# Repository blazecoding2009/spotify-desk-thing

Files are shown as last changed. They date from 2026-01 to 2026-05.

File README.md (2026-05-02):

# spotify desk thing
### custom made pcb to be like the [spotify car thing](https://support.spotify.com/us/article/car-thing-discontinued/) (sadly discontinued)

yeah this is something i literally thought of while sitting and listening to music and i think it'd look cool lol
the whole project is pretty self-explanatory, a replacement to the spotify desk think, you could use this as a deskpad with diff firmware too!!






## Features

- ESP32-S3
- 3.5” 480×320 SPI TFT display
- Capacitive touchscreen (GT911)
- SD card music playback
- I²S DAC (PCM5242)
- Differential headphone amp (TPA6132A2)
- Rotary encoder for volume + play/pause
- Headphone output (3.5mm jack)

---

## Hardware Overview

### Main Components

- **ESP32-S3-WROOM-1**
- **ST7796 3.5” TFT Display**
- **GT911 Capacitive Touch (on display)**
- **PCM5242 DAC**
- **TPA6132A2 Headphone Amplifier**
- **MicroSD Card **
- **Rotary Encoder with push button**

## Firmware Overview

The firmware is written using **ESP-IDF**.

### Tasks

- **UI Task**
  - Draws the interface
  - Handles play/pause and volume updates

- **Input Task**
  - Reads touch input
  - Reads rotary encoder events
  - Pushes events into a queue

- **Audio Task**
  - Plays WAV files
  - Handles beeps and stop commands
 
## Future Ideas

- Spotify / Wi-Fi streaming
- Album art
- Playlists
- Battery power
- Better UI animations

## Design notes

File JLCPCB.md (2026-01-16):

PCBA Type	Economic
Assembly Side	Top Side
PCBA Qty 2
Tooling holes	Added by JLCPCB
Confirm Parts Placement	No
Bake Components	No
Photo Confirmation	No
Board Cleaning	No
Conformal Coating (cleaning included)	No
Packaging	Antistatic bubble film
Depanel boards & edge rail before delivery	No
Solder Paste	High temp.
Flying Probe Test	No
Add paste for unpopulated pad & step stencil opening	No
Nitrogen reflow soldering	Yes (for Economic)
Function test	No
PCBA remark	No
File provided as	Complete File, just proceed with my own files
Panel Format	1 * 1
Build Time	3 - 4 days
Stencil Storage	No
Fixture Storage	No
Gross Weight	





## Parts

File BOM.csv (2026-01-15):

Name | Quantity | Cost (CAD) incl. shipping | Cost (USD) | Link
ESP32-S3 N16R8 | 1 | $20.76 | $14.91 | https://www.aliexpress.com/item/1005004815894336.html?mp=1
3.5in IPS Touch Display | 1 | $28.08 | $20.17 | https://www.aliexpress.com/item/1005006112241357.html?mp=1
EC11E Encoder | 1 | $6.41 | $4.61 | https://www.aliexpress.com/item/1005007644083514.html?mp=1
PCB | 1 | $84.88 | $61.25 | JLCPCB
M3x5mm screws | 6 |  |  | already have
M3 5mm wide heatset inserts | 6 | $7.20 | $5.20 | https://www.aliexpress.com/item/1005006838108683.html?curPageLogUid=nqhrvDMGyt7B
3d printed case | 1 |  |  | by me
 |  | Total | $107.87

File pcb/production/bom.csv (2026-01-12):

Designator | Footprint | Quantity | Value | LCSC Part #
BOOT1 | SW_SPST_CK_KMS2xxG | 1 | BOOT | C221784
C1, C12, C13, C18, C4, C6, C8 | 0402 | 7 | 0.1uF | C1525
C10, C15, C7 | 0402 | 3 | 1uF | C52923
C11, C19 | 0402 | 2 | 10uF | C15525
C14, C16, C2, C5, C9 | 0402 | 5 | 2.2uF | C12530
C17 | 0603 | 1 | 1uF | C15849
C3 | 0402 | 1 | 22uF | C415703
F1 | FUSC1608X100N | 1 | 0603L100SLYR | C207017
J1 | USB_C_Receptacle_HRO_TYPE-C-31-M-12 | 1 | USB_C_Receptacle_USB2.0_16P | C165948
J2 | CUI_SJ-3523-SMT-TR | 1 | AudioJack3_Ground | C4991872
J3 | TE_1-1734839-4_1x14-1MP_P0.5mm_Horizontal | 1 | ST7796
L1 | 0805 | 1 | 2.2uH | C1043
PS1 | SON50P200X200X80-9N | 1 | TPS62162DSGR | C40256
R1, R2, R3, R4, R5 | 0603 | 5 | 10k | C25804
R10, R9 | 0603 | 2 | 27ohm | C25190
R11, R7 | 0603 | 2 | 10ohm | C22859
R12, R13 | 0603 | 2 | 4.7k | C23162
R14, R8 | 0402 | 2 | 5.1k | C25905
R6 | 0603 | 1 | 100k | C25803
RESET1 | SW_SPST_CK_KMS2xxG | 1 | RESET | C221784
U1 | RHB32_3P45X3P45_TEX | 1 | PCM5242RHBR
U2 | WQFN-16-1EP_3x3mm_P0.5mm_EP1.6x1.6mm_ThermalVias | 1 | TPA6132A2RTER | TPA6132A2RTER
U3 | EC11E18244A5_ALPS | 1 | EC11E18244A5
U4 | XCVR_ESP32-S3-WROOM-1-N4 | 1 | ESP32-S3-WROOM-1-N16R8
U5 | SOT-23-6 | 1 | USBLC6-2SC6

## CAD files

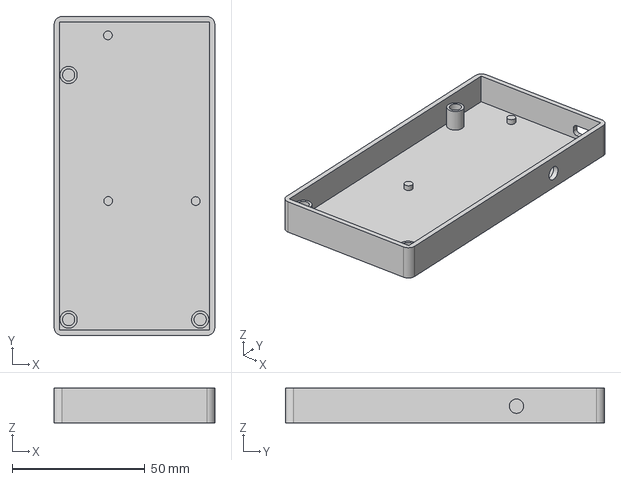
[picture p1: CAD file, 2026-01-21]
case/case_bottom.step
60.4 x 120.0 x 13.0 mm

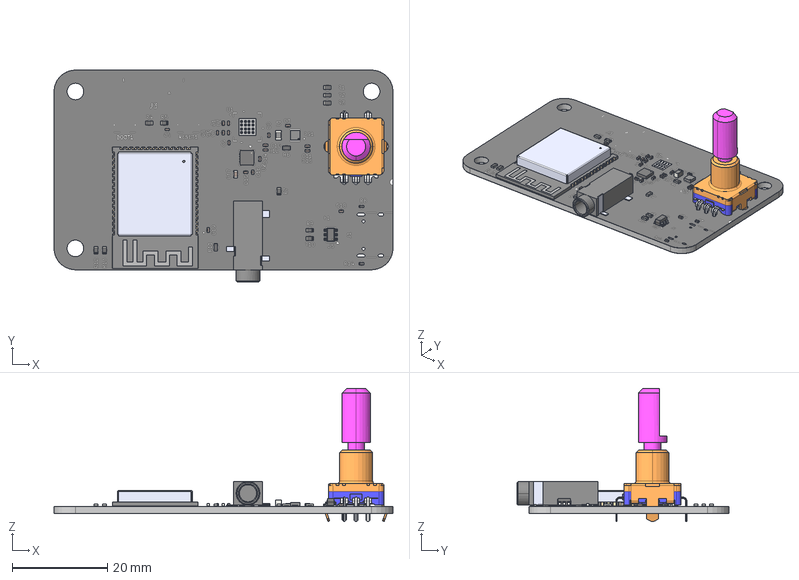
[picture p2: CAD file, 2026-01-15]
pcb/spotify desk thing.step
71.3 x 44.6 x 28.0 mm
R_0402_1005Metric x 2
C_0402_1005Metric x 18
R_0603_1608Metric x 12
SJ-3523-SMT-TR
SOT-23-6
TPS62162DSGR
L_0805_2012Metric
WQFN-16-1EP_3x3mm_P0.5mm_EP1.6x1.6mm
C_0603_1608Metric
ESP32-S3-WROOM-1-N4
ec11e18244a5
spotify desk thing_silkscreen x 2
spotify desk thing_soldermask x 2
spotify desk thing_PCB

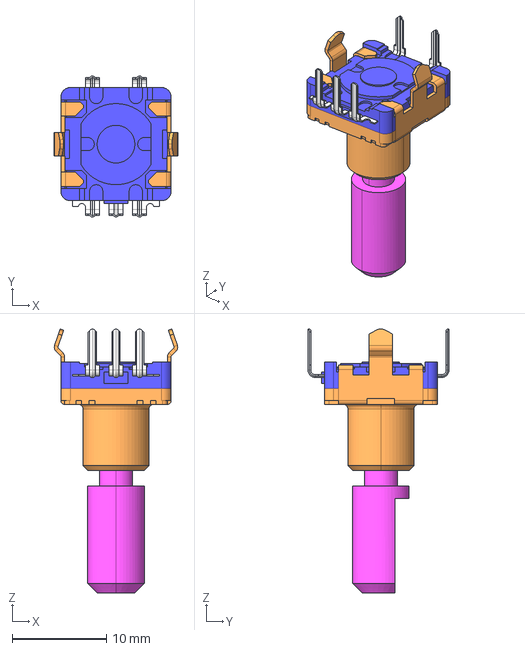
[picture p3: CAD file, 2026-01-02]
pcb/symbols/EC11E/ec11e18244a5.stp
13.1 x 15.0 x 28.0 mm

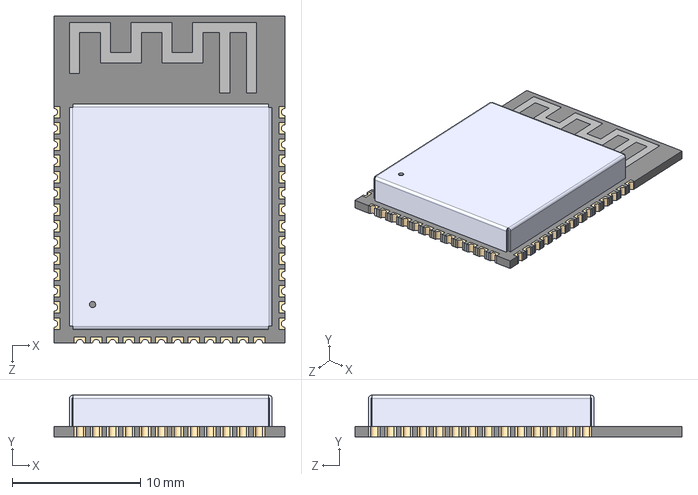
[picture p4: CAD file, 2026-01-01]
pcb/symbols/ESP32_S3_WROOM_1_N4/ESP32-S3-WROOM-1-N4.step
18.0 x 3.25 x 25.5 mm

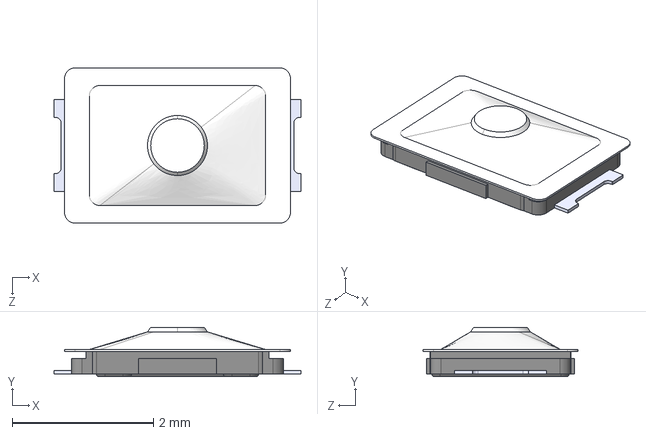
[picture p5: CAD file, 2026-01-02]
pcb/symbols/EVP_AWED4A/EVP-AWED4A.step
3.50 x 0.7 x 2.20 mm

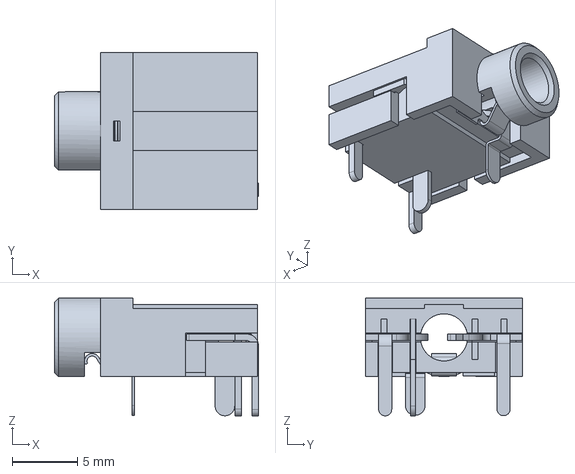
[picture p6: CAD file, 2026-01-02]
pcb/symbols/Lumberg_KLBR_4.stp
15.6 x 12.0 x 9.00 mm

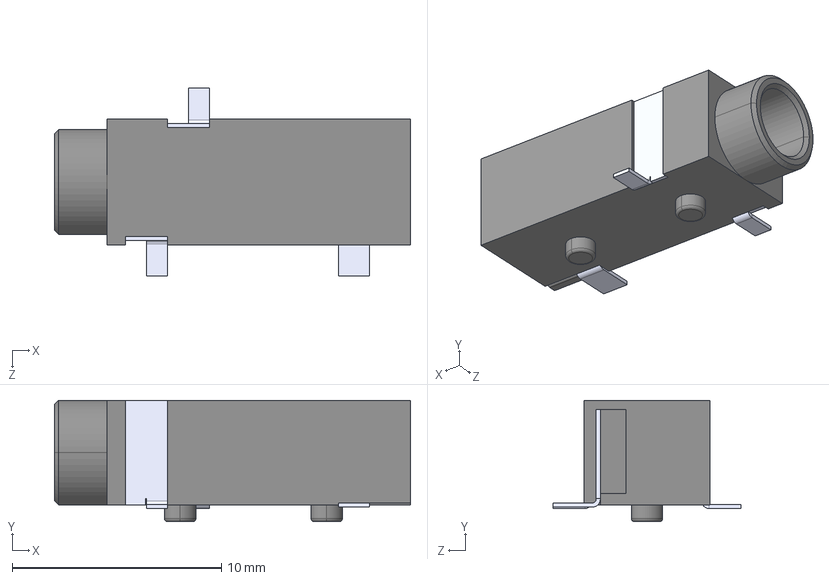
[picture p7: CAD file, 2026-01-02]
pcb/symbols/SJ_3523_SMT_TR/SJ-3523-SMT-TR.step
17.0 x 5.80 x 9.00 mm

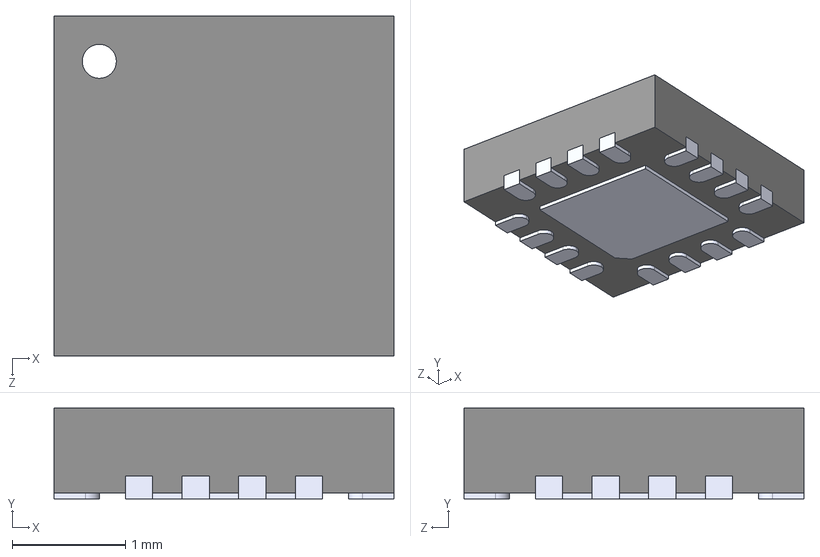
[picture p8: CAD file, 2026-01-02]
pcb/symbols/TPA6132A2RTER/TPA6132A2RTER.step
3.00 x 0.8 x 3.00 mm

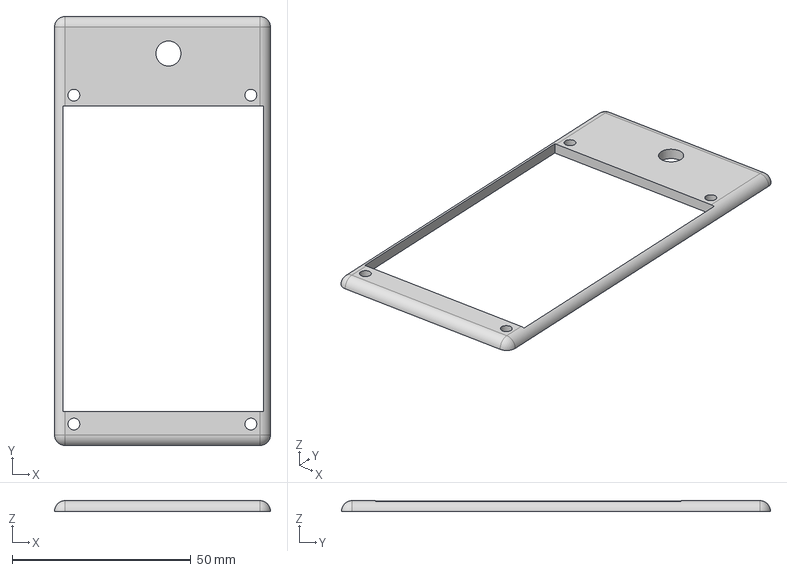
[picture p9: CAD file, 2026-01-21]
case/case_top.step
60.4 x 120.0 x 3.00 mm

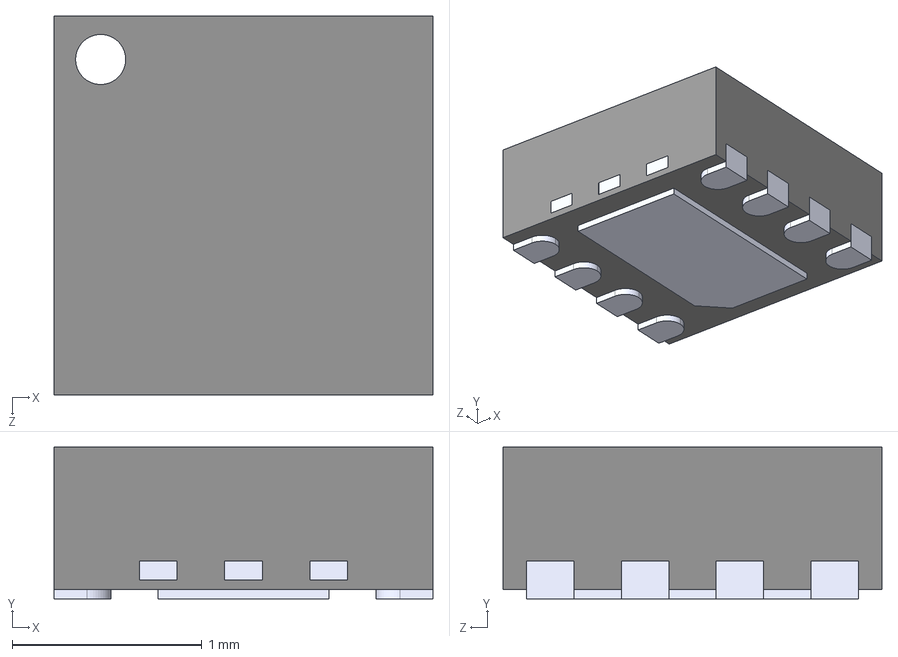
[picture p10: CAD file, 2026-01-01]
pcb/symbols/TPS62162DSGR/TPS62162DSGR.step
2.00 x 0.8 x 2.00 mm

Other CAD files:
case/case.f3z
pcb/spotify desk thing.stl

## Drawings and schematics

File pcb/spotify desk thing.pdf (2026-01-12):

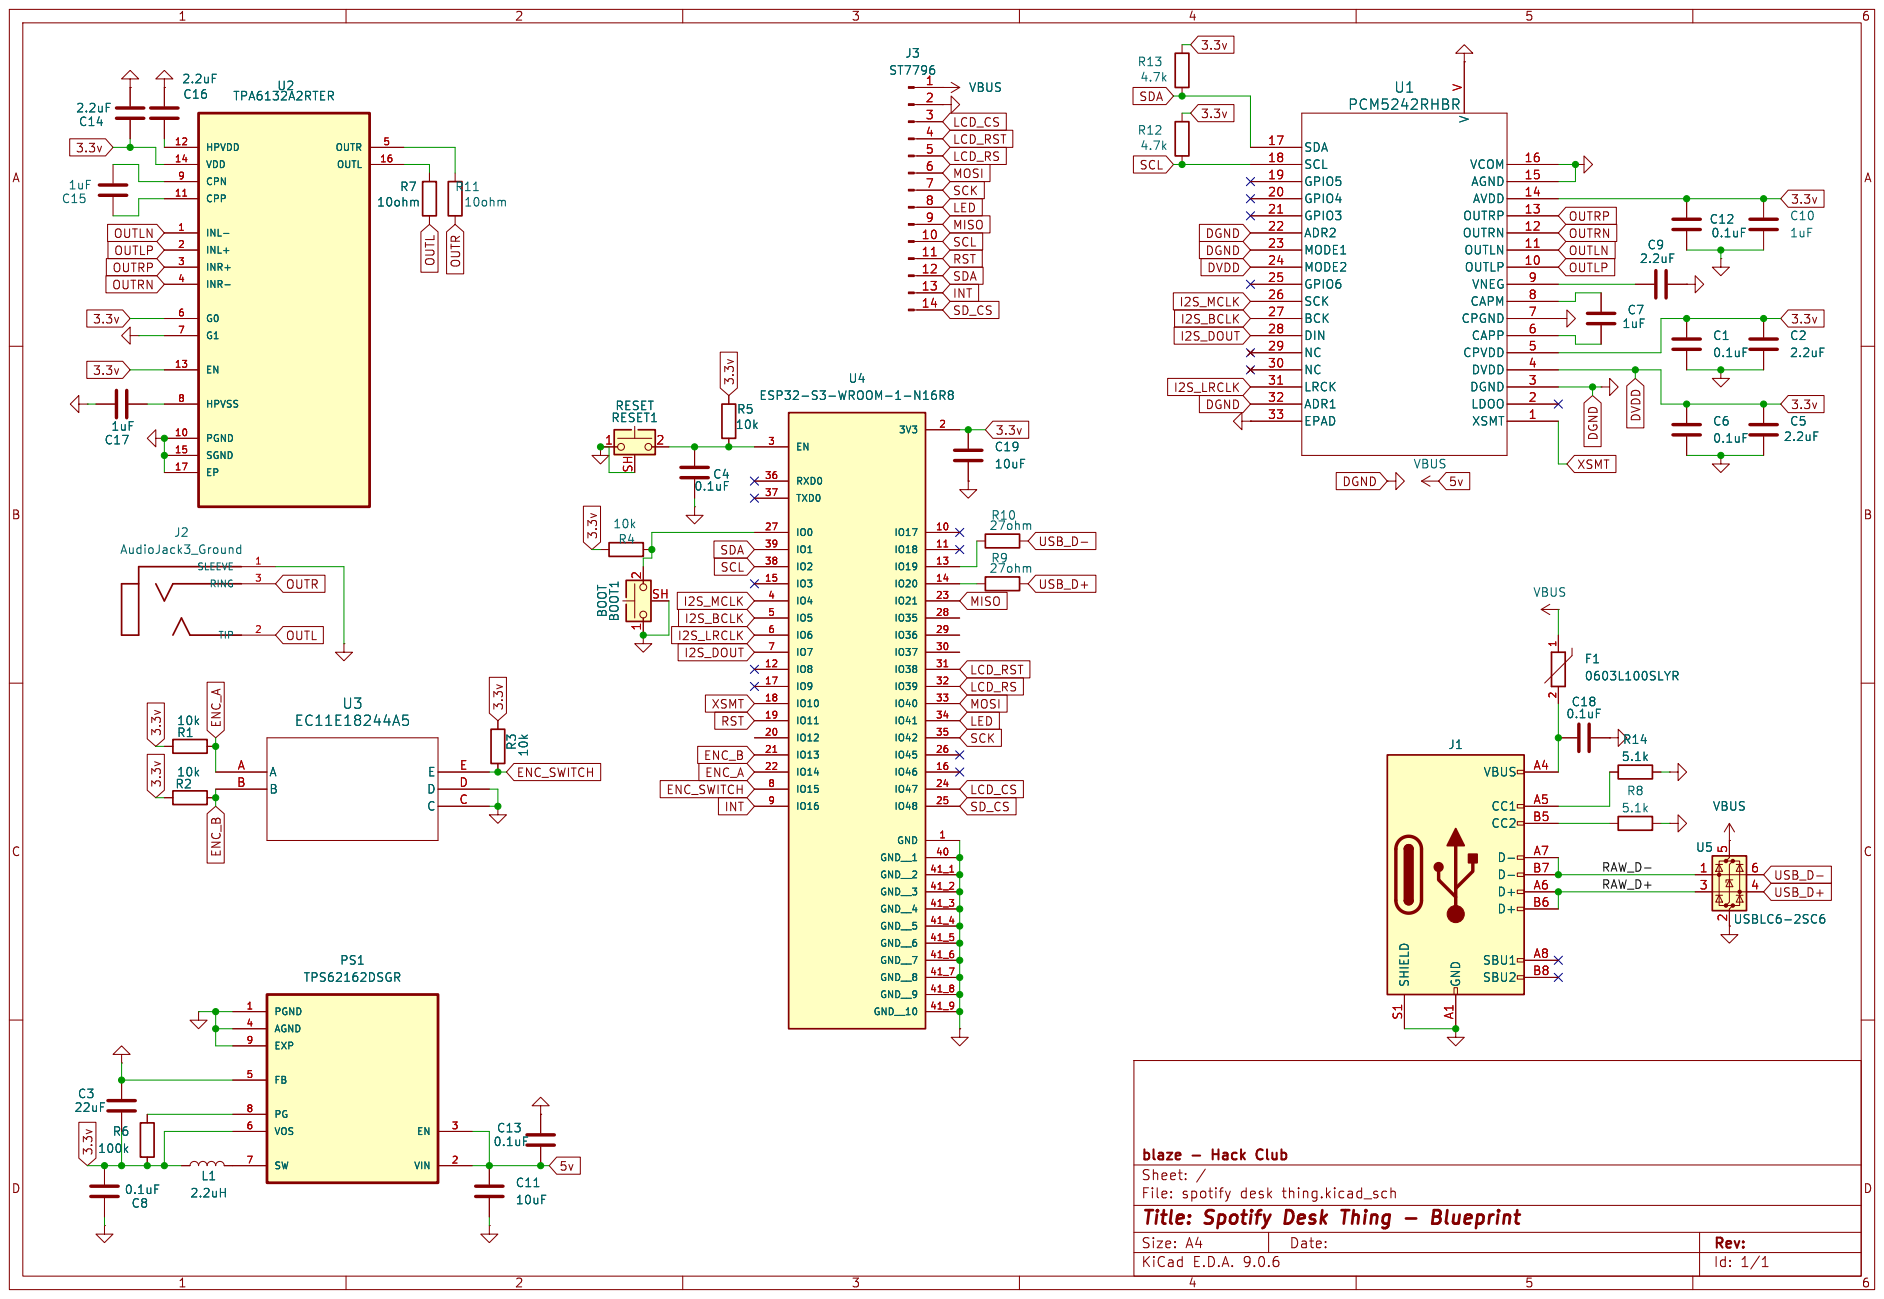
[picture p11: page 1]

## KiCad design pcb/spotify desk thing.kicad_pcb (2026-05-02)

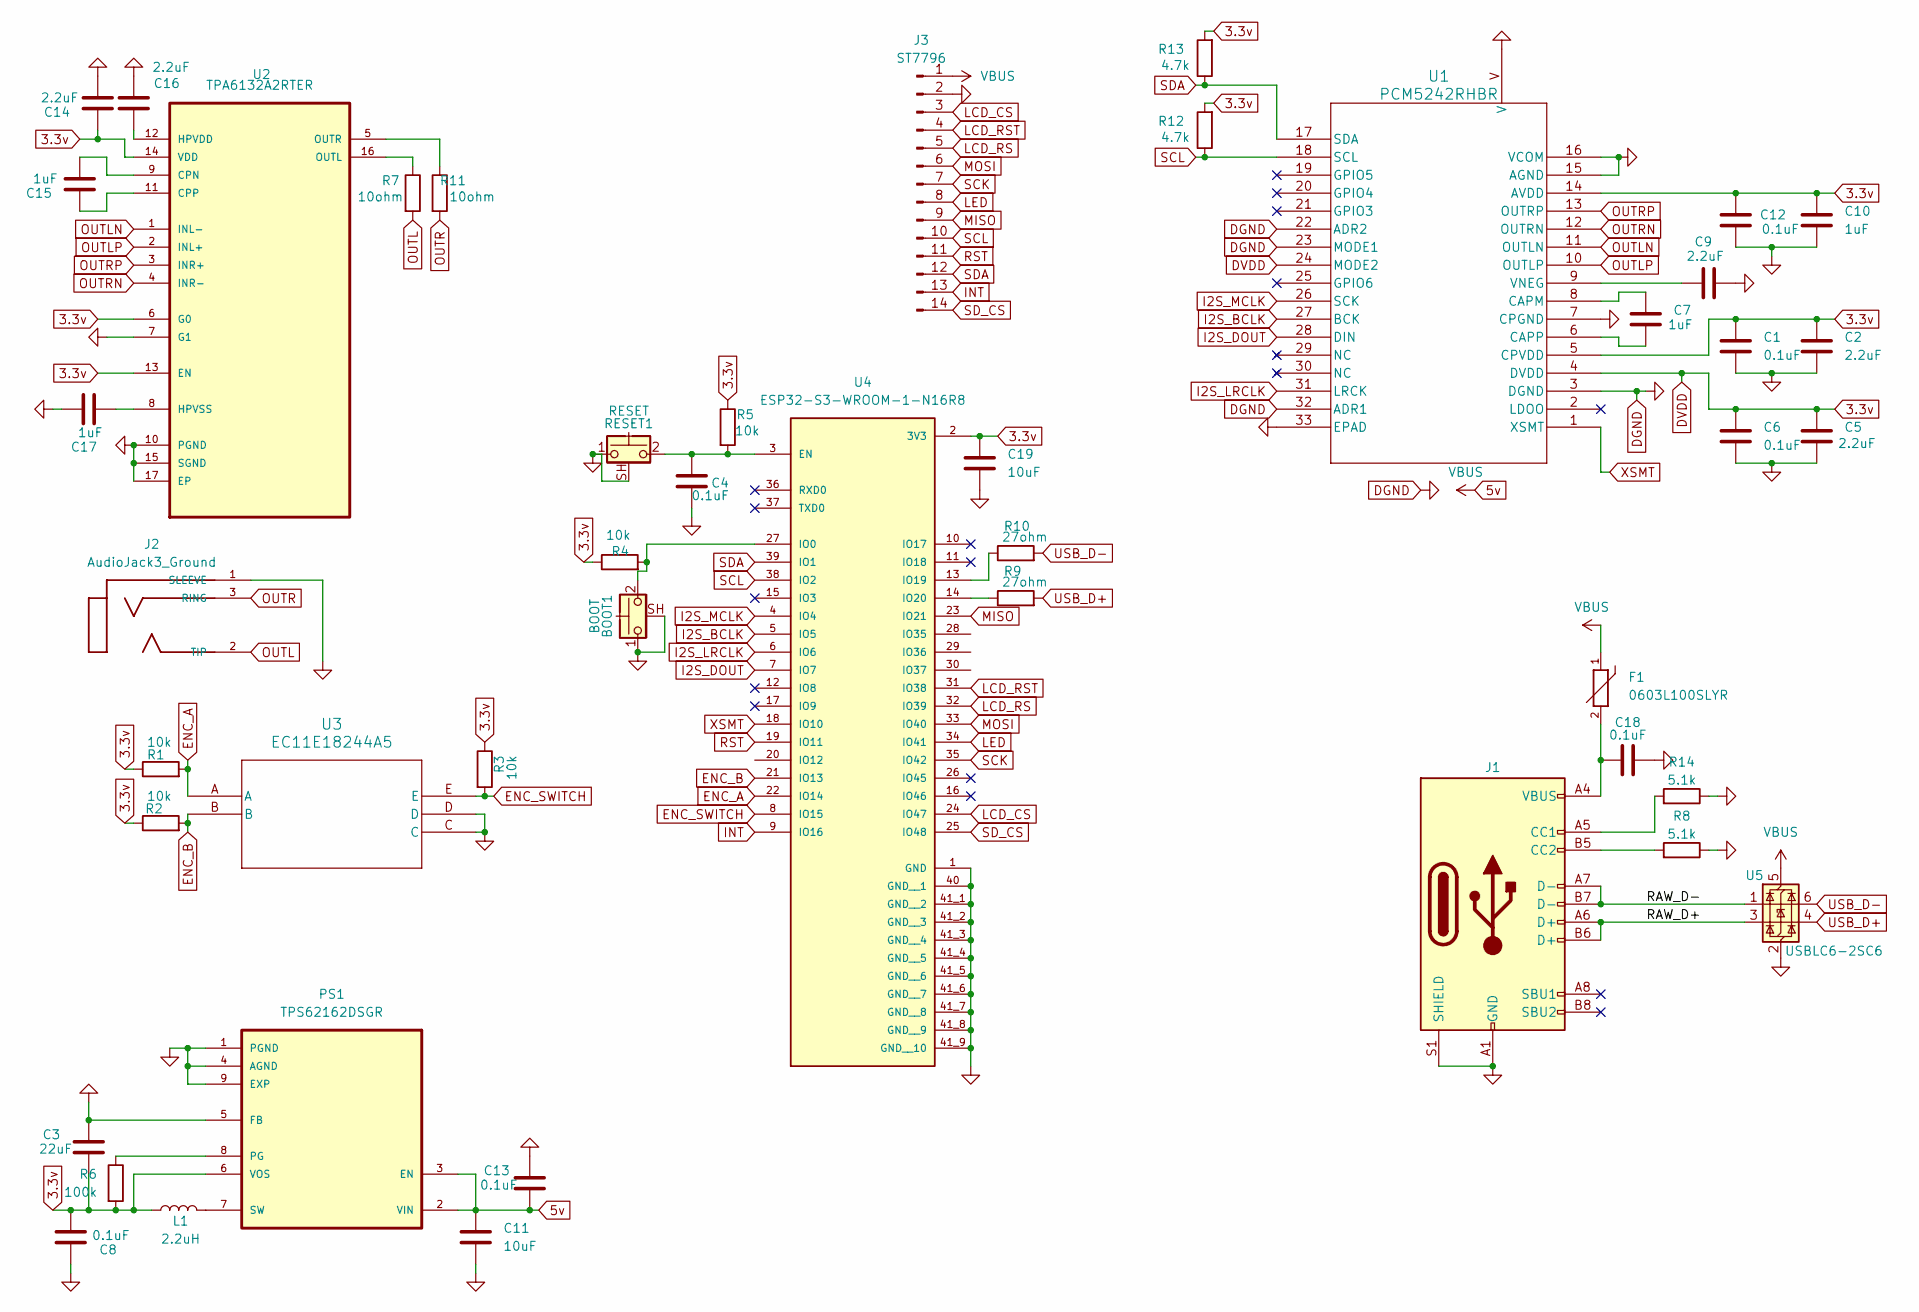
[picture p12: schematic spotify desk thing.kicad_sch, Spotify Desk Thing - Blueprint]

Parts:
BOOT1: BOOT; SW_SPST_CK_KMS2xxG; Part # KSR211GLFS; LCSC Part # C221784
C1, C6, C8, C12, C13, C18: 0.1uF; C_0402_1005Metric; Part # TCC0402X5R105K6R3AT; LCSC Part # C1525
C2, C5, C9, C14, C16: 2.2uF; C_0402_1005Metric; Part # TCC0402X5R105K6R3AT; LCSC Part # C12530
C3: 22uF; C_0402_1005Metric; Part # TCC0402X5R105K6R3AT; LCSC Part # C415703
C4: 0.1uF; C_0402_1005Metric; Part # GCM155R71H104KE02J; LCSC Part # C1525
C7, C10, C15: 1uF; C_0402_1005Metric; Part # TCC0402X5R105K6R3AT; LCSC Part # C52923
C11, C19: 10uF; C_0402_1005Metric; Part # TCC0402X5R105K6R3AT; LCSC Part # C15525
C17: 1uF; C_0603_1608Metric; Part # TCC0402X5R105K6R3AT; LCSC Part # C15849
F1: 0603L100SLYR; FUSC1608X100N; PARTREV GD 05.07.21; LCSC Part # C207017
J1: USB_C_Receptacle_USB2.0_16P; USB_C_Receptacle_HRO_TYPE-C-31-M-12; LCSC Part # C165948
J2: AudioJack3_Ground; CUI_SJ-3523-SMT-TR; LCSC Part # C4991872
J3: ST7796; TE_1-1734839-4_1x14-1MP_P0.5mm_Horizontal
L1: 2.2uH; L_0805_2012Metric; Part # WI0805LD101KST-C-HF; LCSC Part # C1043
PS1: TPS62162DSGR; SON50P200X200X80-9N; PARTREV E; LCSC Part # C40256
R1, R3, R4, R5: 10k; R_0603_1608Metric; Part # RC1206JR-134K7L; LCSC Part # C25804
R2: 10k; R_0603_1608Metric; Part # RC1206JR-134K7L; LCSC C25804
R6: 100k; R_0603_1608Metric; Part # RC1206JR-134K7L; LCSC Part # C25803
R7, R11: 10ohm; R_0603_1608Metric; Part # RC1206JR-134K7L; LCSC Part # C22859
R8, R14: 5.1k; R_0402_1005Metric; Part # RMCF0805JT5K10; LCSC Part # C25905
R9, R10: 27ohm; R_0603_1608Metric; Part # RC1206JR-134K7L; LCSC Part # C25190
R12, R13: 4.7k; R_0603_1608Metric; Part # RC1206JR-134K7L; LCSC Part # C23162
RESET1: RESET; SW_SPST_CK_KMS2xxG; Part # KSR211GLFS; LCSC Part # C221784
U1: PCM5242RHBR; RHB32_3P45X3P45_TEX
U2: TPA6132A2RTER; WQFN-16-1EP_3x3mm_P0.5mm_EP1.6x1.6mm_ThermalVias; MPN TPA6132A2RTER
U3: EC11E18244A5; EC11E18244A5_ALPS
U4: ESP32-S3-WROOM-1-N16R8; XCVR_ESP32-S3-WROOM-1-N4; PARTREV v1.0
U5: USBLC6-2SC6; SOT-23-6

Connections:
3.3v: C1.1, C2.1, C3.1, C5.1, C6.1, C8.1, C10.1, C12.1, C14.1, C19.1, L1.1, PS1.6 (VOS), R1.1, R2.1, R3.1, R4.1, R5.1, R6.2, R12.2, R13.2, U1.4 (DVDD), U1.5 (CPVDD), U1.14 (AVDD), U1.24 (MODE2), U2.6 (G0), U2.13 (EN), U2.14 (VDD), U4.2 (3V3)
5v: C11.1, C13.1, F1.1, J3.1, PS1.2 (VIN), PS1.3 (EN), U5.5 (VBUS)
/RAW_D+: J1.A6 (D+), J1.B6 (D+), U5.3 (I/O2)
/RAW_D-: J1.A7 (D-), J1.B7 (D-), U5.1 (I/O1)
DGND: BOOT1.1, BOOT1.SH (B), C1.2, C2.2, C3.2, C4.2, C5.2, C6.2, C8.2, C9.2, C10.2, C11.2, C12.2, C13.2, C14.2, C16.2, C17.1, C18.2, C19.2, J1.A1 (GND), J1.A12 (GND), J1.B1 (GND), J1.B12 (GND), J1.S1 (SHIELD), J2.1 (SLEEVE), J3.2, PS1.1 (PGND), PS1.4 (AGND), PS1.5 (FB), PS1.9 (EXP), R8.1, R14.1, RESET1.1, RESET1.SH (B), U1.3 (DGND), U1.7 (CPGND), U1.15 (AGND), U1.16 (VCOM), U1.22 (ADR2), U1.23 (MODE1), U1.32 (ADR1), U1.33 (EPAD), U1.V, U2.7 (G1), U2.10 (PGND), U2.15 (SGND), U2.17 (EP), U3.C, U3.D, U4.1 (GND), U4.40 (GND__1), U4.41_1 (GND__2), U4.41_2 (GND__3), U4.41_3 (GND__4), U4.41_4 (GND__5), U4.41_5 (GND__6), U4.41_6 (GND__7), U4.41_7 (GND__8), U4.41_8 (GND__9), U4.41_9 (GND__10), U5.2 (GND)
ENC_A: R1.2, U3.A, U4.22 (IO14)
ENC_B: R2.2, U3.B, U4.21 (IO13)
ENC_SWITCH: R3.2, U3.E, U4.8 (IO15)
I2S_BCLK: U1.27 (BCK), U4.5 (IO5)
I2S_DOUT: U1.28 (DIN), U4.7 (IO7)
I2S_LRCLK: U1.31 (LRCK), U4.6 (IO6)
I2S_MCLK: U1.26 (SCK), U4.4 (IO4)
INT: J3.13, U4.9 (IO16)
LCD_CS: J3.3, U4.24 (IO47)
LCD_RS: J3.5, U4.32 (IO39)
LCD_RST: J3.4, U4.31 (IO38)
LED: J3.8, U4.34 (IO41)
MISO: J3.9, U4.23 (IO21)
MOSI: J3.6, U4.33 (IO40)
unnamed: C18.1, F1.2, J1.A4 (VBUS), J1.A9 (VBUS), J1.B4 (VBUS), J1.B9 (VBUS)
unnamed: J1.A5 (CC1), R14.2
unnamed: J1.B5 (CC2), R8.2
unnamed: PS1.8 (PG), R6.1
unnamed: L1.2, PS1.7 (SW)
unnamed: C7.1, U1.8 (CAPM)
unnamed: C7.2, U1.6 (CAPP)
unnamed: C9.1, U1.9 (VNEG)
unnamed: C15.2, U2.9 (CPN)
unnamed: C15.1, U2.11 (CPP)
unnamed: C16.1, U2.12 (HPVDD)
unnamed: C17.2, U2.8 (HPVSS)
unnamed: R7.1, U2.16 (OUTL)
unnamed: R11.1, U2.5 (OUTR)
unnamed: C4.1, R5.2, RESET1.2, U4.3 (EN)
unnamed: BOOT1.2, R4.2, U4.27 (IO0)
unnamed: R10.1, U4.13 (IO19)
unnamed: R9.1, U4.14 (IO20)
OUTL: J2.2 (TIP), R7.2
OUTLN: U1.11 (OUTLN), U2.1 (INL-)
OUTLP: U1.10 (OUTLP), U2.2 (INL+)
OUTR: J2.3 (RING), R11.2
OUTRN: U1.12 (OUTRN), U2.4 (INR-)
OUTRP: U1.13 (OUTRP), U2.3 (INR+)
RST: J3.11, U4.19 (IO11)
SCK: J3.7, U4.35 (IO42)
SCL: J3.10, R12.1, U1.18 (SCL), U4.38 (IO2)
SDA: J3.12, R13.1, U1.17 (SDA), U4.39 (IO1)
SD_CS: J3.14, U4.25 (IO48)
USB_D+: R9.2, U5.4 (I/O2)
USB_D-: R10.2, U5.6 (I/O1)
XSMT: U1.1 (XSMT), U4.18 (IO10)

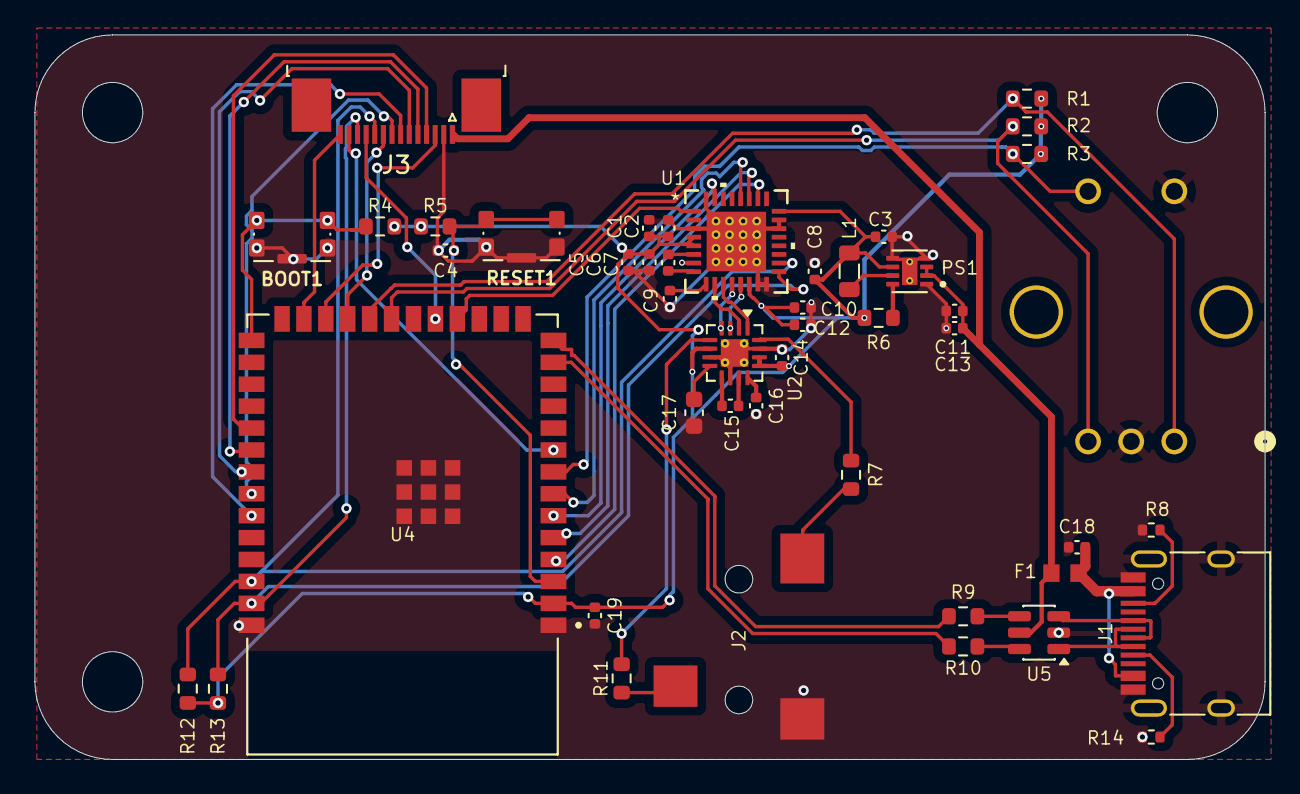
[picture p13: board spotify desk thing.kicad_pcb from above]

Board: 2 copper layers, 71.3 x 42.0 mm, 46 parts (1 on the bottom side), 51 nets.

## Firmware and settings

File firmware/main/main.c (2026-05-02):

// spotify desk thing
// by blaze
// this took painful hours to get to work and build. 
// i spent ages making it look pretty too. don't diss me. 

#include "dirent.h"
#include <stdio.h>
#include <string.h>
#include <strings.h>
#include <unistd.h>
#include <fcntl.h>

#include "audio.h"
#include "encoder.h"
#include "esp_check.h"
#include "esp_log.h"
#include "esp_timer.h"
#include "esp_vfs_fat.h"
#include "freertos/FreeRTOS.h"
#include "freertos/queue.h"
#include "freertos/task.h"
#include "driver/gpio.h"
#include "driver/i2c.h"
#include "driver/sdspi_host.h"
#include "driver/spi_master.h"
#include "gt911.h"
#include "ili9488.h"
#include "nvs_flash.h"
#include "sdmmc_cmd.h"
#include "ui.h"
#include "pcm5242.h"

#define TAG "SPOTIFY_DESK"

#ifndef CONFIG_TFT_SPI_SPEED_HZ
#define CONFIG_TFT_SPI_SPEED_HZ (20 * 1000 * 1000)
#endif

#define SCREEN_MOSI GPIO_NUM_40
#define SCREEN_MISO GPIO_NUM_21
#define SCREEN_SCLK GPIO_NUM_42
#define SCREEN_CS GPIO_NUM_47
#define SCREEN_DC GPIO_NUM_39
#define SCREEN_RES GPIO_NUM_38
#define SCREEN_BL GPIO_NUM_41
#define SD_CS GPIO_NUM_48

#define I2C_SDA GPIO_NUM_1
#define I2C_SCL GPIO_NUM_2
#define TOUCH_INT GPIO_NUM_16

#define ENC_A GPIO_NUM_13
#define ENC_B GPIO_NUM_14
#define ENC_SW GPIO_NUM_15

#define I2S_MCLK GPIO_NUM_4
#define I2S_BCLK GPIO_NUM_5
#define I2S_LRCLK GPIO_NUM_6
#define I2S_DIN GPIO_NUM_7

// PCM5242 DAC control pins
#define PCM5242_I2C_ADDR 0x48      // Default I2C address for PCM5242
#define PCM5242_XSMT GPIO_NUM_10   // Soft mute control (active low)

#define MUSIC_DIR "/sd/music"

typedef enum {
	INPUT_EVENT_TOUCH = 0,
	INPUT_EVENT_ENCODER_LEFT,
	INPUT_EVENT_ENCODER_RIGHT,
	INPUT_EVENT_ENCODER_BUTTON,
} input_event_type_t;

typedef struct {
	input_event_type_t type;
	union {
		struct {
			uint16_t x;
			uint16_t y;
		} touch;
	} data;
} input_event_t;

typedef enum {
	AUDIO_CMD_BEEP = 0,
	AUDIO_CMD_PLAY_WAV,
	AUDIO_CMD_STOP,
} audio_command_type_t;

typedef struct {
	audio_command_type_t type;
	char path[256];
} audio_command_t;

static QueueHandle_t input_queue;
static QueueHandle_t audio_queue;

static spi_device_handle_t lcd_spi = NULL;
static ili9488_t lcd = {0};
static gt911_handle_t *touch_handle = NULL;
static encoder_handle_t *encoder_handle = NULL;
static ui_context_t ui_ctx;
static sdmmc_card_t *mounted_card = NULL;
static char default_track[256] = {0};
static char default_track_name[64] = {0};
static volatile bool touch_flag = false;

// I2C device array
#define MAX_I2C_DEVICES 10
static uint8_t found_i2c_devices[MAX_I2C_DEVICES] = {0};
static uint8_t num_i2c_devices = 0;

static void IRAM_ATTR touch_interrupt(void *arg) {
	(void)arg;
	touch_flag = true;
}

static void init_nvs(void) {
	esp_err_t ret = nvs_flash_init();
	if (ret == ESP_ERR_NVS_NO_FREE_PAGES || ret == ESP_ERR_NVS_NEW_VERSION_FOUND) {
		ESP_ERROR_CHECK(nvs_flash_erase());
		ESP_ERROR_CHECK(nvs_flash_init());
	}
}

static esp_err_t init_spi_bus(void) {
	spi_bus_config_t buscfg = {
		.mosi_io_num = SCREEN_MOSI,
		.miso_io_num = SCREEN_MISO,
		.sclk_io_num = SCREEN_SCLK,
		.quadwp_io_num = -1,
		.quadhd_io_num = -1,
		.max_transfer_sz = 320 * 40 * 2,
	};
	ESP_RETURN_ON_ERROR(spi_bus_initialize(SPI2_HOST, &buscfg, SPI_DMA_CH_AUTO), TAG, "SPI bus init failed");

	spi_device_interface_config_t devcfg = {
		.clock_speed_hz = CONFIG_TFT_SPI_SPEED_HZ,
		.mode = 0,
		.spics_io_num = SCREEN_CS,
		.queue_size = 7,
		.flags = SPI_DEVICE_NO_DUMMY,
	};
	return spi_bus_add_device(SPI2_HOST, &devcfg, &lcd_spi);
}

static esp_err_t init_display(void) {
	ili9488_config_t cfg = {
		.spi = lcd_spi,
		.dc_pin = SCREEN_DC,
		.reset_pin = SCREEN_RES,
		.backlight_pin = -1,
		.backlight_active_high = true,
	};
	ESP_RETURN_ON_ERROR(ili9488_init(&lcd, &cfg), TAG, "LCD init failed");
	return ili9488_fill_color(&lcd, 0, 0, ILI9488_WIDTH, ILI9488_HEIGHT, 0x0000);
}

static esp_err_t mount_sd(void) {
	sdmmc_host_t host = SDSPI_HOST_DEFAULT();
	host.slot = SPI2_HOST;
	host.max_freq_khz = 20000;

	esp_vfs_fat_sdmmc_mount_config_t mount_config = {
		.format_if_mount_failed = false,
		.max_files = 8,
		.allocation_unit_size = 16 * 1024,
	};

	sdspi_device_config_t slot_config = SDSPI_DEVICE_CONFIG_DEFAULT();
	slot_config.host_id = SPI2_HOST;
	slot_config.gpio_cs = SD_CS;
	slot_config.gpio_cd = SDSPI_SLOT_NO_CD;
	slot_config.gpio_wp = SDSPI_SLOT_NO_WP;

	esp_err_t ret = esp_vfs_fat_sdspi_mount("/sd", &host, &slot_config, &mount_config, &mounted_card);
	if (ret != ESP_OK) {
		ESP_LOGE(TAG, "Failed to mount SD card: %s", esp_err_to_name(ret));
		return ret;
	}

	sdmmc_card_print_info(stdout, mounted_card);
	return ESP_OK;
}

static void list_music_files(const char *path) {
	DIR *dir = opendir(path);
	if (!dir) {
		ESP_LOGW(TAG, "Directory %s not found", path);
		return;
	}
	struct dirent *entry;
	ESP_LOGI(TAG, "Listing %s", path);
	while ((entry = readdir(dir)) != NULL) {
		if (entry->d_name[0] == '.') {
			continue;
		}
		ESP_LOGI(TAG, "  %s", entry->d_name);
	}
	closedir(dir);
}

static bool find_first_wav(const char *path, char *out_path, size_t len) {
	DIR *dir = opendir(path);
	if (!dir) {
		return false;
	}
	struct dirent *entry;
	while ((entry = readdir(dir)) != NULL) {
		char *dot = strrchr(entry->d_name, '.');
		if (!dot) {
			continue;
		}
		if (strcasecmp(dot, ".wav") == 0) {
			snprintf(out_path, len, "%s/%s", path, entry->d_name);
			closedir(dir);
			return true;
		}
	}
	closedir(dir);
	return false;
}

static esp_err_t init_touch(void) {
	gt911_config_t cfg = {
		.i2c_port = I2C_NUM_0,
		.sda_pin = I2C_SDA,
		.scl_pin = I2C_SCL,
		.int_pin = TOUCH_INT,
		.i2c_clock_hz = 400000,
	};
	ESP_RETURN_ON_ERROR(gt911_init(&touch_handle, &cfg), TAG, "GT911 init failed");
	return gt911_set_interrupt_callback(touch_handle, touch_interrupt, NULL);
}

static esp_err_t init_encoder(void) {
	encoder_config_t cfg = {
		.pin_a = ENC_A,
		.pin_b = ENC_B,
		.pin_button = ENC_SW,
		.button_active_level_low = true,
		.debounce_ms = 5,
	};
	return encoder_init(&encoder_handle, &cfg);
}

static esp_err_t init_i2c_bus(void) {
	// Initialize I2C bus - used by both GT911 and PCM5242
	i2c_config_t i2c_conf = {
		.mode = I2C_MODE_MASTER,
		.sda_io_num = I2C_SDA,
		.sda_pullup_en = GPIO_PULLUP_ENABLE,
		.scl_io_num = I2C_SCL,
		.scl_pullup_en = GPIO_PULLUP_ENABLE,
		.master.clk_speed = 400000,
	};
	ESP_RETURN_ON_ERROR(i2c_param_config(I2C_NUM_0, &i2c_conf), TAG, "I2C param config failed");
	ESP_RETURN_ON_ERROR(i2c_driver_install(I2C_NUM_0, i2c_conf.mode, 0, 0, 0), TAG, "I2C driver install failed");
	return ESP_OK;
}

static void scan_i2c_quick(void) {
	printf("SPOTIFY_DESK: Quick I2C device scan:\n");
	int found_count = 0;
	for (uint8_t addr = 1; addr < 127; addr++) {
		i2c_cmd_handle_t cmd = i2c_cmd_link_create();
		i2c_master_start(cmd);
		i2c_master_write_byte(cmd, (addr << 1) | I2C_MASTER_WRITE, true);
		i2c_master_stop(cmd);
		
		esp_err_t ret = i2c_master_cmd_begin(I2C_NUM_0, cmd, pdMS_TO_TICKS(100));
		i2c_cmd_link_delete(cmd);
		
		if (ret == ESP_OK) {
			printf("  Found device at 0x%02X\n", addr);
			found_count++;
		}
	}
	printf("SPOTIFY_DESK: I2C scan complete - found %d devices\n", found_count);
}

static esp_err_t init_audio(void) {
	// Initialize PCM5242 DAC via I2C (non-fatal if it fails)
	pcm5242_config_t pcm5242_cfg = {
		.i2c_port = I2C_NUM_0,
		.xsmt_pin = PCM5242_XSMT,
	};
	esp_err_t pcm5242_ret = pcm5242_init(&pcm5242_cfg);
	if (pcm5242_ret != ESP_OK) {
		printf("SPOTIFY_DESK: Warning - PCM5242 init failed (0x%x)\n", pcm5242_ret);
	}
	
	// Initialize I2S for audio output
	audio_i2s_config_t cfg = {
		.port = I2S_NUM_0,
		.mclk_pin = I2S_MCLK,
		.bclk_pin = I2S_BCLK,
		.lrclk_pin = I2S_LRCLK,
		.dout_pin = I2S_DIN,
		.sample_rate_hz = 44100,
	};
	return audio_init(&cfg);
}

static void input_task(void *arg) {
	(void)arg;
	const TickType_t delay = pdMS_TO_TICKS(15);
	gt911_touch_data_t touch_data = {0};
	encoder_event_t enc_event = {0};

	while (true) {
		if (touch_handle) {
			if (gt911_read_touch_points(touch_handle, &touch_data) == ESP_OK && touch_data.num_points > 0) {
				input_event_t evt = {
					.type = INPUT_EVENT_TOUCH,
					.data.touch = {
						.x = touch_data.points[0].x,
						.y = touch_data.points[0].y,
					},
				};
				evt.data.touch.x = evt.data.touch.x >= ILI9488_WIDTH ? ILI9488_WIDTH - 1 : evt.data.touch.x;
				evt.data.touch.y = evt.data.touch.y >= ILI9488_HEIGHT ? ILI9488_HEIGHT - 1 : evt.data.touch.y;
				printf("TOUCH: X=%u, Y=%u\n", evt.data.touch.x, evt.data.touch.y);
				fflush(stdout);
				ESP_LOGI(TAG, "Touch: %u,%u", evt.data.touch.x, evt.data.touch.y);
				xQueueSend(input_queue, &evt, 0);
			}
		}
		vTaskDelay(delay);

		while (encoder_get_event(encoder_handle, &enc_event, 0)) {
			input_event_t evt = {.type = INPUT_EVENT_TOUCH};
			switch (enc_event.type) {
				case ENCODER_EVENT_LEFT:
					evt.type = INPUT_EVENT_ENCODER_LEFT;
					break;
				case ENCODER_EVENT_RIGHT:
					evt.type = INPUT_EVENT_ENCODER_RIGHT;
					break;
				case ENCODER_EVENT_BUTTON:
					evt.type = INPUT_EVENT_ENCODER_BUTTON;
					break;
				default:
					evt.type = INPUT_EVENT_TOUCH;
					break;
			}
			if (evt.type != INPUT_EVENT_TOUCH) {
				xQueueSend(input_queue, &evt, 0);
			}
		}
		vTaskDelay(delay);
	}
}

static void audio_task(void *arg) {
	(void)arg;
	audio_command_t cmd;
	while (true) {
		if (xQueueReceive(audio_queue, &cmd, portMAX_DELAY) == pdPASS) {
			switch (cmd.type) {
				case AUDIO_CMD_BEEP:
					audio_play_beep(880.0f, 120, 0.35f);
					break;
				case AUDIO_CMD_PLAY_WAV:
					ESP_LOGI(TAG, "Playing %s", cmd.path);
					audio_play_wav_file(cmd.path);
					break;
				case AUDIO_CMD_STOP:
					audio_request_stop();
					break;
				default:
					break;
			}
		}
	}
}

static void ui_task(void *arg) {
	(void)arg;
	input_event_t evt;
	ui_draw_boot_screen(&ui_ctx);

	audio_command_t beep = {.type = AUDIO_CMD_BEEP};
	xQueueSend(audio_queue, &beep, portMAX_DELAY);

	while (true) {
		if (xQueueReceive(input_queue, &evt, portMAX_DELAY) != pdPASS) {
			continue;
		}

		switch (evt.type) {
			case INPUT_EVENT_ENCODER_LEFT: {
				uint8_t vol = ui_ctx.volume_percent > 5 ? ui_ctx.volume_percent - 5 : 0;
				ui_set_volume(&ui_ctx, vol);
				break;
			}
			case INPUT_EVENT_ENCODER_RIGHT: {
				uint8_t vol = ui_ctx.volume_percent + 5;
				if (vol > 100) {
					vol = 100;
				}
				ui_set_volume(&ui_ctx, vol);
				break;
			}
			case INPUT_EVENT_ENCODER_BUTTON: {
				bool new_state = !ui_ctx.is_playing;
				ui_set_play_state(&ui_ctx, new_state);
				if (new_state) {
					if (default_track[0] != '\0') {
						audio_command_t play = {
							.type = AUDIO_CMD_PLAY_WAV,
						};
						strncpy(play.path, default_track, sizeof(play.path) - 1);
						play.path[sizeof(play.path) - 1] = '\0';
						xQueueSend(audio_queue, &play, portMAX_DELAY);
						const char *name = default_track_name[0] ? default_track_name : default_track;
						ui_set_track(&ui_ctx, name);
					} else {
						ESP_LOGW(TAG, "No WAV file available");
						ui_set_play_state(&ui_ctx, false);
					}
				} else {
					audio_request_stop();
				}
				break;
			}
			case INPUT_EVENT_TOUCH:
				ESP_LOGI(TAG, "Touch event forwarded to UI");
				break;
			default:
				break;
		}
	}
}

void console_echo_task(void *arg) {
	(void)arg;
	printf("Console Echo Started\n");
	fflush(stdout);
	
	char buffer[256];
	int pos = 0;
	
	// Set stdin to non-blocking mode
	int flags = fcntl(STDIN_FILENO, F_GETFL, 0);
	fcntl(STDIN_FILENO, F_SETFL, flags | O_NONBLOCK);
	
	while (1) {
		// Non-blocking read
		int c = getchar();
		if (c != EOF) {
			// Store in buffer
			if (pos < (int)sizeof(buffer) - 1) {
				buffer[pos++] = c;
				if (c == '\n') {
					buffer[pos] = '\0';
					// Print with echo: prefix
					printf("echo: %s", buffer);
					fflush(stdout);
					pos = 0;
				}
			}
		}
		
		// Always yield to prevent watchdog timeout
		vTaskDelay(pdMS_TO_TICKS(100));
	}
}

void encoder_monitor_task(void *arg) {
	(void)arg;
	encoder_handle_t *encoder = (encoder_handle_t *)arg;
	encoder_event_t event;
	
	while (1) {
		if (encoder_get_event(encoder, &event, pdMS_TO_TICKS(100))) {
			switch (event.type) {
				case ENCODER_EVENT_LEFT:
					printf("ENCODER: Moving LEFT\n");
					fflush(stdout);
					break;
				case ENCODER_EVENT_RIGHT:
					printf("ENCODER: Moving RIGHT\n");
					fflush(stdout);
					break;
				case ENCODER_EVENT_BUTTON:
					printf("ENCODER: Button pressed\n");
					fflush(stdout);
					break;
				default:
					break;
			}
		}
		vTaskDelay(pdMS_TO_TICKS(10));
	}
}

void tone_task(void *arg) {
	(void)arg;
	
	// Play 1kHz tone continuously
	while (1) {
		audio_play_beep(1000.0f, 500, 0.5f);  // 1kHz, 0.5 second, 50% volume
		vTaskDelay(pdMS_TO_TICKS(100));  // Small delay between tones
	}
}

static uint16_t ui_color(uint8_t r, uint8_t g, uint8_t b) {
	return ((r & 0xF8) << 8) | ((g & 0xFC) << 3) | (b >> 3);
}

static void ui_draw_char(ui_context_t *ctx, int x, int y, char c, uint8_t scale, uint16_t fg, uint16_t bg) {
	// Simple character drawing - create a filled rectangle for now
	uint8_t char_width = 5 * scale;
	uint8_t char_height = 7 * scale;
	ili9488_fill_color(ctx->display, x, y, char_width, char_height, fg);
}

static void ui_draw_text(ui_context_t *ctx, int x, int y, const char *text, uint8_t scale, uint16_t fg, uint16_t bg) {
	if (!text) {
		return;
	}
	int cursor_x = x;
	for (const char *p = text; *p; ++p) {
		if (*p == '\n') {
			cursor_x = x;
			y += (7 + 2) * scale;
			continue;
		}
		ui_draw_char(ctx, cursor_x, y, *p, scale, fg, bg);
		cursor_x += (5 + 1) * scale;
	}
}

static void scan_i2c_devices(void) {
	num_i2c_devices = 0;
	printf("Scanning I2C bus...\n");
	
	// Scan addresses 0x00 to 0x7F
	for (uint8_t addr = 1; addr < 127; addr++) {
		i2c_cmd_handle_t cmd = i2c_cmd_link_create();
		i2c_master_start(cmd);
		i2c_master_write_byte(cmd, (addr << 1) | I2C_MASTER_WRITE, true);
		i2c_master_stop(cmd);
		
		esp_err_t ret = i2c_master_cmd_begin(I2C_NUM_0, cmd, pdMS_TO_TICKS(100));
		i2c_cmd_link_delete(cmd);
		
		if (ret == ESP_OK && num_i2c_devices < MAX_I2C_DEVICES) {
			found_i2c_devices[num_i2c_devices] = addr;
			num_i2c_devices++;
			printf("Found I2C device at 0x%02X\n", addr);
		}
	}
	printf("I2C scan complete. Found %d devices.\n", num_i2c_devices);
}

void display_task(void *arg) {
	(void)arg;
	
	// Scan I2C bus on startup
	vTaskDelay(pdMS_TO_TICKS(500));
	scan_i2c_devices();
	
	while (1) {
		// Clear screen with black background
		ili9488_fill_color(&lcd, 0, 0, ILI9488_WIDTH, ILI9488_HEIGHT, 0x0000);
		
		// Display I2C devices
		uint16_t white = ui_color(255, 255, 255);
		uint16_t black = ui_color(0, 0, 0);
		
		char i2c_text[256] = {0};
		snprintf(i2c_text, sizeof(i2c_text), "I2C Devices: %d found", num_i2c_devices);
		
		// Draw title
		ili9488_fill_color(&lcd, 0, 0, ILI9488_WIDTH, 30, white);
		
		// Draw device list
		int y_offset = 50;
		for (int i = 0; i < num_i2c_devices && i < 15; i++) {
			char device_str[32];
			snprintf(device_str, sizeof(device_str), "0x%02X", found_i2c_devices[i]);
			
			// Alternate colors for visibility
			uint16_t color = (i % 2 == 0) ? ui_color(0, 255, 0) : ui_color(0, 255, 255);
			ili9488_fill_color(&lcd, 20, y_offset + (i * 25), 280, 20, color);
			y_offset += 5;
		}
		
		vTaskDelay(pdMS_TO_TICKS(5000));
	}
}

void app_main(void) {
	printf("SPOTIFY_DESK: Starting up\n");
	
	// Initialize SPI bus for display
	printf("SPOTIFY_DESK: Initializing SPI bus\n");
	ESP_ERROR_CHECK(init_spi_bus());
	printf("SPOTIFY_DESK: SPI bus initialized\n");
	
	// Initialize display
	printf("SPOTIFY_DESK: Initializing display\n");
	ESP_ERROR_CHECK(init_display());
	printf("SPOTIFY_DESK: Display initialized\n");
	
	// Initialize I2C bus (required by both touch and audio)
	printf("SPOTIFY_DESK: Initializing I2C bus\n");
	ESP_ERROR_CHECK(init_i2c_bus());
	printf("SPOTIFY_DESK: I2C bus initialized\n");
	
	// Scan I2C devices to diagnose what's on the bus
	scan_i2c_quick();
	
	// Initialize touch (non-fatal if it fails)
	printf("SPOTIFY_DESK: Initializing touch\n");
	esp_err_t touch_ret = init_touch();
	if (touch_ret != ESP_OK) {
		printf("SPOTIFY_DESK: Touch init failed (0x%x), continuing without touch\n", touch_ret);
		touch_handle = NULL;
	} else {
		printf("SPOTIFY_DESK: Touch initialized\n");
	}
	
	// Initialize audio
	printf("SPOTIFY_DESK: Initializing audio\n");
	ESP_ERROR_CHECK(init_audio());
	printf("SPOTIFY_DESK: Audio initialized\n");
	
	// Initialize encoder
	printf("SPOTIFY_DESK: Initializing encoder\n");
	encoder_config_t cfg = {
		.pin_a = ENC_A,
		.pin_b = ENC_B,
		.pin_button = ENC_SW,
		.button_active_level_low = true,
		.debounce_ms = 5,
	};
	ESP_ERROR_CHECK(encoder_init(&encoder_handle, &cfg));
	printf("SPOTIFY_DESK: Encoder initialized\n");
	
	// Create input queue
	input_queue = xQueueCreate(10, sizeof(input_event_t));
	
	// Create tasks for input handling, encoder monitoring, tone playing, and display
	xTaskCreatePinnedToCore(input_task, "input", 2048, NULL, 4, NULL, 0);
	xTaskCreatePinnedToCore(encoder_monitor_task, "encoder_monitor", 2048, (void *)encoder_handle, 5, NULL, 0);
	xTaskCreatePinnedToCore(tone_task, "tone", 2048, NULL, 4, NULL, 1);
	xTaskCreatePinnedToCore(display_task, "display", 4096, NULL, 3, NULL, 0);
	
	// Keep main task alive
	while (1) {
		vTaskDelay(pdMS_TO_TICKS(1000));
	}
}

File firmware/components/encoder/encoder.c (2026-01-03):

#include "encoder.h"

#include <stdlib.h>

#include "esp_check.h"
#include "esp_log.h"
#include "esp_timer.h"

#define TAG "ENCODER"
#define ENCODER_QUEUE_LENGTH 16

struct encoder_handle_s {
    encoder_config_t cfg;
    QueueHandle_t queue;
    volatile uint8_t last_state;
    volatile int64_t last_step_us;
    volatile int64_t last_button_us;
};

static const int8_t transition_table[16] = {
    0, -1, 1, 0,
    1, 0, 0, -1,
    -1, 0, 0, 1,
    0, 1, -1, 0
};

static void send_event_from_isr(encoder_handle_t *handle, encoder_event_type_t type) {
    encoder_event_t event = {
        .type = type,
        .timestamp = xTaskGetTickCountFromISR(),
    };
    BaseType_t hp_task = pdFALSE;
    xQueueSendFromISR(handle->queue, &event, &hp_task);
    if (hp_task == pdTRUE) {
        portYIELD_FROM_ISR();
    }
}

static void IRAM_ATTR encoder_ab_isr(void *arg) {
    encoder_handle_t *handle = (encoder_handle_t *)arg;
    uint8_t a = gpio_get_level(handle->cfg.pin_a);
    uint8_t b = gpio_get_level(handle->cfg.pin_b);
    uint8_t current_state = (a << 1) | b;
    uint8_t index = ((handle->last_state << 2) | current_state) & 0x0F;
    int8_t movement = transition_table[index];
    handle->last_state = current_state;
    if (movement != 0) {
        int64_t now = esp_timer_get_time();
        if (now - handle->last_step_us >= (int64_t)handle->cfg.debounce_ms * 1000) {
            handle->last_step_us = now;
            send_event_from_isr(handle, movement > 0 ? ENCODER_EVENT_RIGHT : ENCODER_EVENT_LEFT);
        }
    }
}

static void IRAM_ATTR encoder_button_isr(void *arg) {
    encoder_handle_t *handle = (encoder_handle_t *)arg;
    int level = gpio_get_level(handle->cfg.pin_button);
    bool active = handle->cfg.button_active_level_low ? level == 0 : level == 1;
    if (!active) {
        return;
    }
    int64_t now = esp_timer_get_time();
    if (now - handle->last_button_us >= (int64_t)handle->cfg.debounce_ms * 1000) {
        handle->last_button_us = now;
        send_event_from_isr(handle, ENCODER_EVENT_BUTTON);
    }
}

esp_err_t encoder_init(encoder_handle_t **out_handle, const encoder_config_t *config) {
    if (!out_handle || !config) {
        return ESP_ERR_INVALID_ARG;
    }

    encoder_handle_t *handle = calloc(1, sizeof(encoder_handle_t));
    if (!handle) {
        return ESP_ERR_NO_MEM;
    }
    handle->cfg = *config;
    handle->queue = xQueueCreate(ENCODER_QUEUE_LENGTH, sizeof(encoder_event_t));
    if (!handle->queue) {
        free(handle);
        return ESP_ERR_NO_MEM;
    }

    gpio_config_t gpio_conf = {
        .mode = GPIO_MODE_INPUT,
        .pull_up_en = GPIO_PULLUP_ENABLE,
        .pull_down_en = GPIO_PULLDOWN_DISABLE,
        .intr_type = GPIO_INTR_ANYEDGE,
    };
    gpio_conf.pin_bit_mask = (1ULL << config->pin_a) | (1ULL << config->pin_b);
    ESP_RETURN_ON_ERROR(gpio_config(&gpio_conf), TAG, "Config AB failed");

    gpio_conf.pin_bit_mask = (1ULL << config->pin_button);
    gpio_conf.intr_type = GPIO_INTR_ANYEDGE;
    gpio_conf.pull_up_en = config->button_active_level_low ? GPIO_PULLUP_ENABLE : GPIO_PULLUP_DISABLE;
    gpio_conf.pull_down_en = config->button_active_level_low ? GPIO_PULLDOWN_DISABLE : GPIO_PULLDOWN_ENABLE;
    ESP_RETURN_ON_ERROR(gpio_config(&gpio_conf), TAG, "Config button failed");

    handle->last_state = ((gpio_get_level(config->pin_a) << 1) | gpio_get_level(config->pin_b)) & 0x03;
    handle->last_step_us = esp_timer_get_time();
    handle->last_button_us = 0;

    esp_err_t err = gpio_install_isr_service(0);
    if (err != ESP_OK && err != ESP_ERR_INVALID_STATE) {
        vQueueDelete(handle->queue);
        free(handle);
        return err;
    }

    ESP_RETURN_ON_ERROR(gpio_isr_handler_add(config->pin_a, encoder_ab_isr, handle), TAG, "ISR A failed");
    ESP_RETURN_ON_ERROR(gpio_isr_handler_add(config->pin_b, encoder_ab_isr, handle), TAG, "ISR B failed");
    ESP_RETURN_ON_ERROR(gpio_isr_handler_add(config->pin_button, encoder_button_isr, handle), TAG, "ISR button failed");

    *out_handle = handle;
    return ESP_OK;
}

bool encoder_get_event(encoder_handle_t *handle, encoder_event_t *event, TickType_t ticks_to_wait) {
    if (!handle || !event) {
        return false;
    }
    if (xQueueReceive(handle->queue, event, ticks_to_wait) == pdPASS) {
        return true;
    }
    return false;
}

void encoder_reset(encoder_handle_t *handle) {
    if (!handle) {
        return;
    }
    xQueueReset(handle->queue);
    handle->last_state = ((gpio_get_level(handle->cfg.pin_a) << 1) | gpio_get_level(handle->cfg.pin_b)) & 0x03;
}

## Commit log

2026-01-01 creating repo
    [spotify desk thing.kicad_pcb, spotify desk thing.kicad_sch]
2026-01-01 wired up 3.3v power and usb c
    [ESP32-S3-WROOM-1-N4.step, TPS62162DSGR.step, spotify desk thing.kicad_sch]
2026-01-02 fixed wiring and wired up AMP
    [TPA6132A2RTER.step]
2026-01-02 moved stuff around and connected lcd/encoder
    [spotify desk thing.kicad_sch]
2026-01-02 deleted unconnected traces
    [spotify desk thing.kicad_sch]
2026-01-02 updated schematic
2026-01-02 routing started
    [spotify desk thing.kicad_pcb, spotify desk thing.kicad_sch]
2026-01-02 more routing
    [EVP-AWED4A.step, freerouting.dsn, spotify desk thing.kicad_pcb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]
2026-01-02 updated stuff to jlc thing
    [Lumberg_KLBR_4.stp, SJ-3523-SMT-TR.step, bom.csv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]
2026-01-02 removed ramdom floating label
    [spotify desk thing.kicad_sch]
2026-01-02 fixed some errors
    [spotify desk thing.kicad_pcb]
2026-01-05 Create BOM.md with pricing information
    Added a Bill of Materials (BOM) with pricing details.
2026-01-05 renaming src to firmware
    [positions.csv]
2026-01-11 Update and rename BOM - Sheet1.csv to BOM.csv
    [BOM.csv]
2026-01-12 updated the stuff to fit the new screen
    Removed old images and added new images for PCB design.
2026-01-12 updated pcb with review changes
    [bom.csv, positions.csv, spotify desk thing.kicad_pcb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]
2026-01-12 oops forgot smtg
    [bom.csv, positions.csv, spotify desk thing.kicad_pcb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]
2026-01-15 Update BOM.csv with new components and quantities
    Added new components and updated quantities in BOM.
    [BOM.csv]
2026-01-15 Update BOM.csv with new items and costs
    [BOM.csv]
2026-01-16 separate case folder
    [case.f3z, case_bottom.stl, case_top.stl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]
2026-01-21 thinner case
    [case.f3z, case_bottom.step, case_bottom.stl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]
